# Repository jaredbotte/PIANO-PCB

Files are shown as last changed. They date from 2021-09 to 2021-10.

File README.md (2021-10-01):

# P.I.A.N.O PCB Repository
This repository currently contains all the KiCad files for the P.I.A.N.O PCB.    

To clone this repository, please run:   
```
git clone https://github.com/jaredbotte/PIANO-PCB.git
cd PIANO-PCB
git submodule init
git submodule update
```

This will ensure that you have all the required parts libraries to view our PCB.

I tried my best to ensure that all paths are relative, but if a path cannot be found, please try looking in the "manage libraries" or "manage footprints" tabs.

TODO: Prune this and include minimal files from external repositories!

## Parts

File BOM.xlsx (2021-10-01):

Part/Description | Quantity | Currently Have | MFG. Number | Supplier Number | Cost | Total | Link
Bulk Capacitor 1000µF | 1 | 0 | 35PX1000MEFC10X20 | 1189-1745-ND | 0.84 | 0.84 | https://www.digikey.com/en/products/detail/rubycon/35PX1000MEFC10X20/3563769
440Ω Resistor 0805 | 1 |  |  |  |  | 0
01x06 Pin Socket | 1 | 0 | 2044-1X07G00SA | 2553-2044-1X07G00SA-ND | 0.33 | 0.33 | https://www.digikey.com/en/products/detail/oupiin/2044-1X07G00SA/13251939
10kΩ Resistor 0805 | 3 |  |  |  |  | 0
AZ1117-3.3 | 1 |  |  |  |  | 0
10µF Capacitor 0805 | 2 |  |  |  |  | 0
0.01µF Capacitor 0805 | 1 |  |  |  |  | 0
0.1µF Capacitor 0805 | 3 |  |  |  |  | 0
DIN 5 180 degree | 1 |  |  |  |  | 0
1N914 Diode | 1 |  |  |  |  | 0
4.7kΩ Resistor 0805 | 1 |  |  |  |  | 0
50kΩ Resistor 0805 | 1 |  |  |  |  | 0
220Ω Resistor 0805 | 4 |  |  |  |  | 0
6N138 Optoisolator | 1 |  |  |  |  | 0
Blue LED 0805 | 1 |  |  |  |  | 0
Green LED 0805 | 1 |  |  |  |  | 0
22µF Capacitor | 1 |  |  |  |  | 0
74AHCT1G125W5-7 | 1 |  |  |  |  | 0
317030213 | 1 | 0 | 317030213 | 1597-1434-ND | 9.9 | 9.9 | https://www.digikey.com/en/products/detail/seeed-technology-co-ltd/317030213/6578366
Barrel Jack | 1 |  |  |  |  | 0
01x07 Pin Socket | 1 | 0 | PPTC071LFBN-RC | S7005-ND | 0.59 | 0.59 | https://www.digikey.com/en/products/detail/sullins-connector-solutions/PPTC071LFBN-RC/810146
6mmx6mm Push Button | 1 |  |  |  |  | 0
MicroSD Socket | 1 |  |  |  |  | 0
Terminal Block Connector | 1 |  |  |  |  | 0
Already Have
Lab
Order
On List

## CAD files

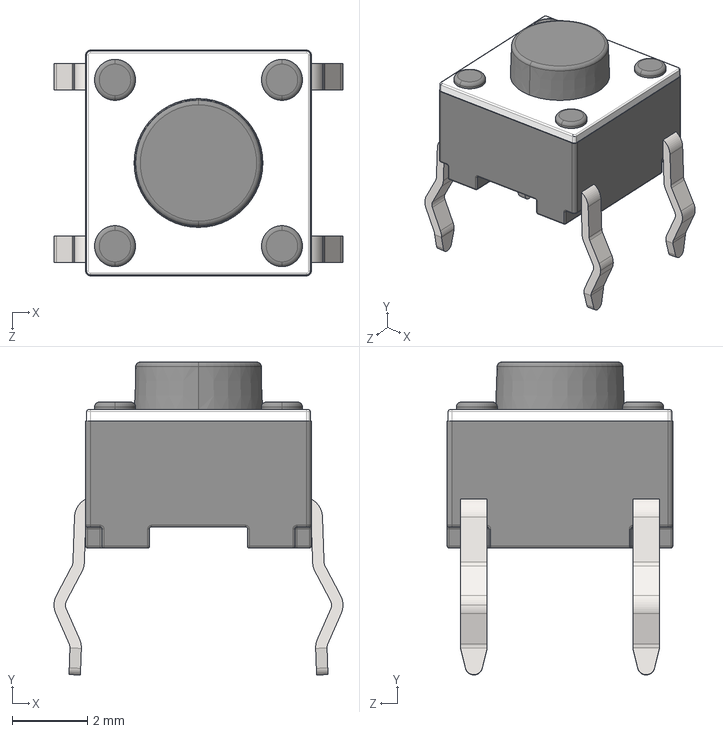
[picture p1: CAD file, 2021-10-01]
Parts/4-1437565-1/tactileswitch-short.STEP
7.69 x 8.33 x 6.01 mm

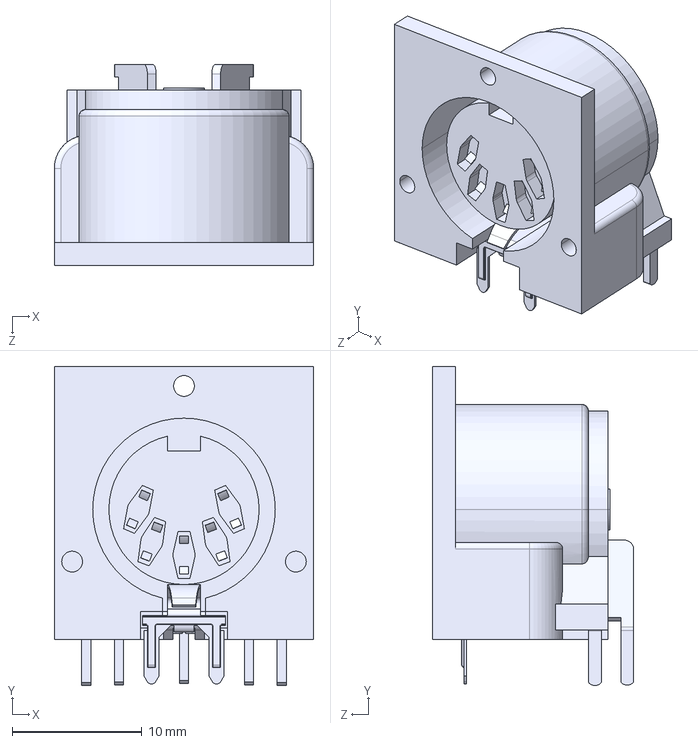
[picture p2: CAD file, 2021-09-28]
Parts/57PC5F/57PC5F--3DModel-STEP-1.STEP
20.0 x 24.5 x 15.5 mm

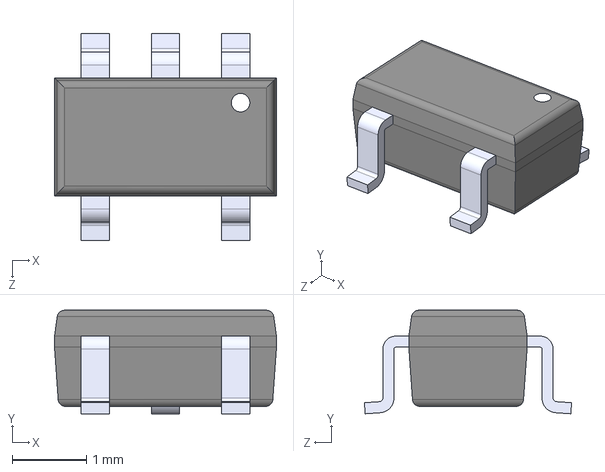
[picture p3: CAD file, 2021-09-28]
Parts/74AHCT1G125W5-7/74AHCT1G125W5-7.step
3.00 x 1.40 x 2.80 mm

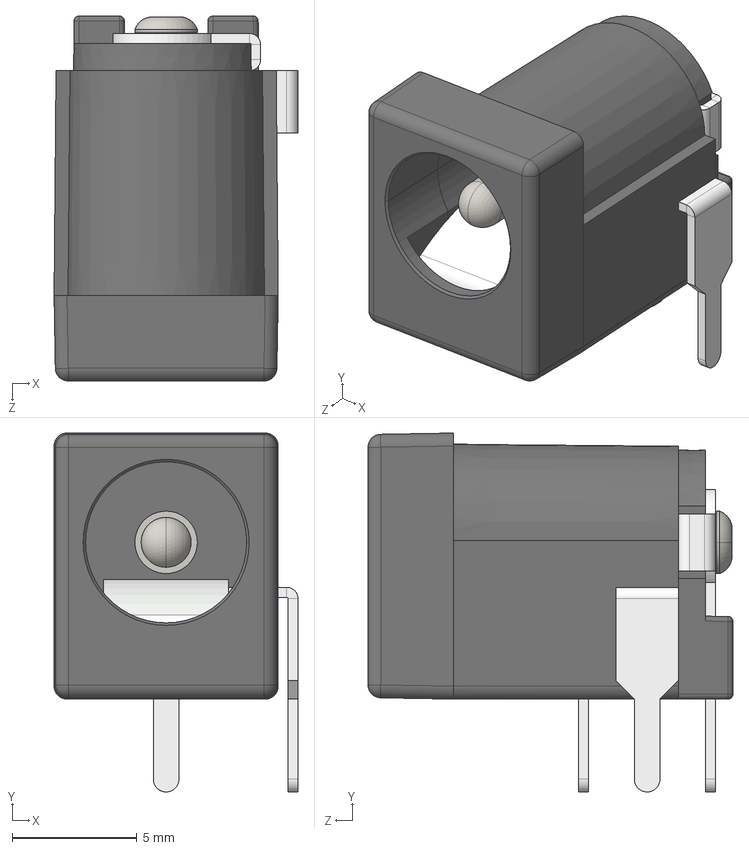
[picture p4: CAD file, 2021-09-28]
Parts/barrel_jack/DC Power Jack 5.5mm x 2.1mm.STEP
9.77 x 14.4 x 14.6 mm

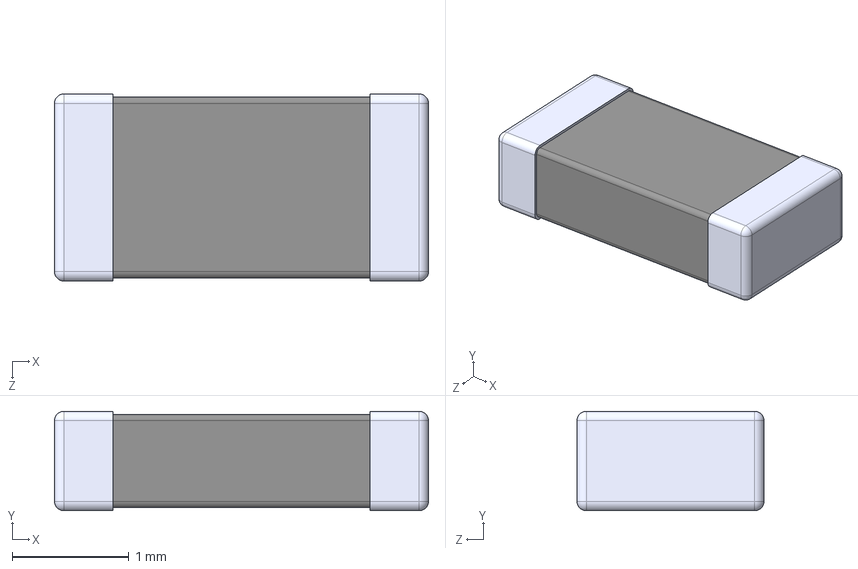
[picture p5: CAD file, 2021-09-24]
Parts/C1206C226M9PACTU/C1206C226M9PACTU.step
3.20 x 0.85 x 1.60 mm

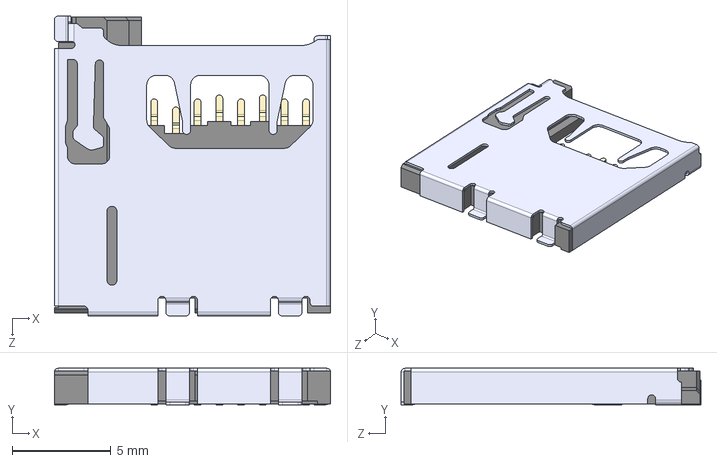
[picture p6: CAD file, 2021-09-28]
Parts/microsd/2908-05WB-MG--3DModel-STEP-56544.STEP
14.0 x 1.85 x 15.2 mm

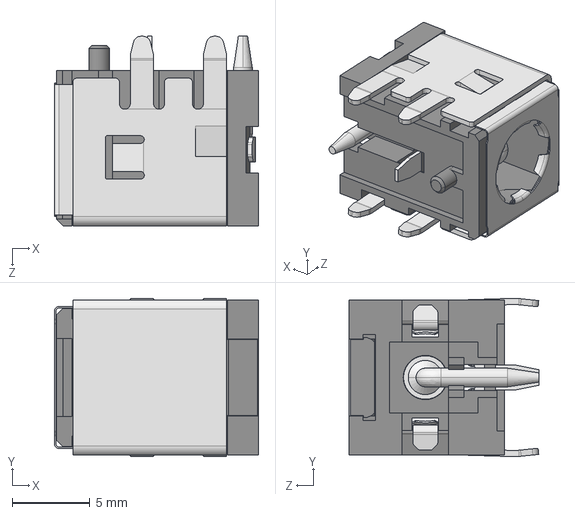
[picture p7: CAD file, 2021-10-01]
Parts/PJ-082BH/CUI_DEVICES_PJ-082BH.step
13.1 x 10.2 x 12.2 mm

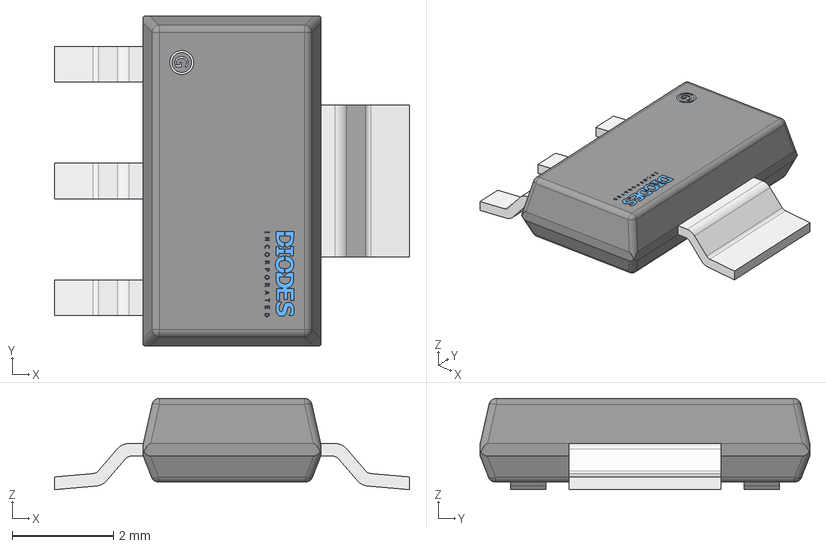
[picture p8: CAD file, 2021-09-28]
Parts/power_regulator/eec.models/Diodes_Inc._-_AZ1117H-3.3TRG1.step
7.00 x 6.50 x 1.80 mm

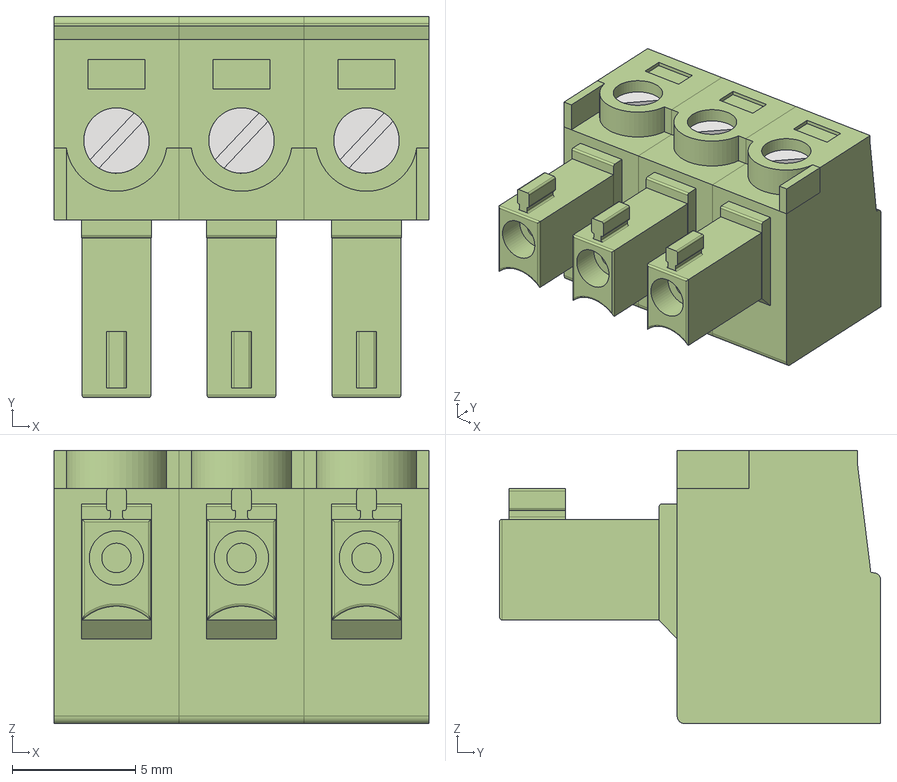
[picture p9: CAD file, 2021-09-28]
Parts/terminal_jack/15EDGK-5.08-03P-14-00A(H).stp
15.2 x 15.5 x 11.1 mm
body_1pc EC350V x 3
body_screw EC350V x 3
body_15edgk_top x 2

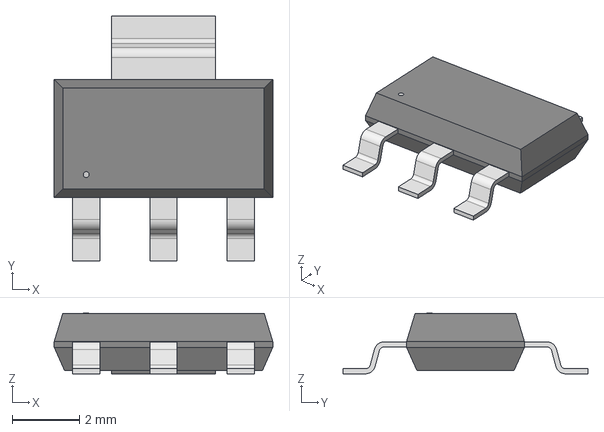
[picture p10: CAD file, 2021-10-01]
Parts/ul_AZ1117IH-3-3TRG1/KiCAD/2021-09-23_22-23-04/SOT223_AZ1117I_6P5X3P5_DIO.step
6.50 x 7.29 x 1.81 mm

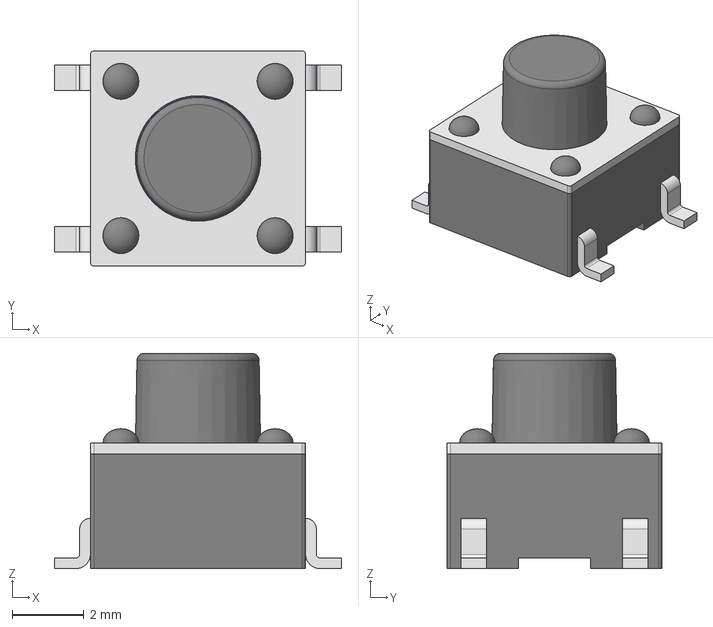
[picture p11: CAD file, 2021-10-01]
Parts/4-1437565-1/TS6-SMT_H-6.0.step
8.00 x 6.00 x 6.00 mm

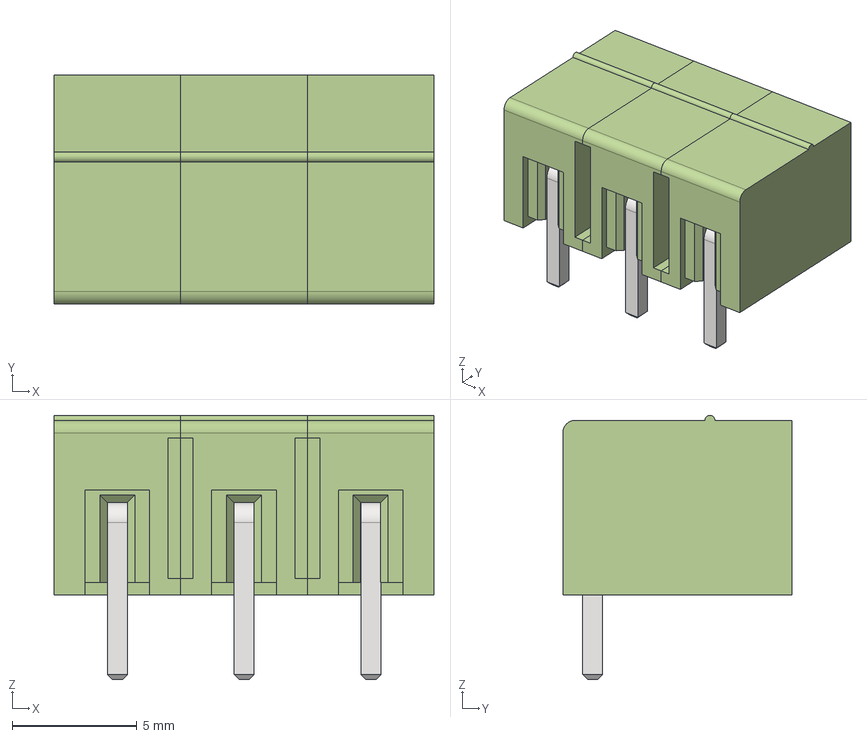
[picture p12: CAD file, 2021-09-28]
Parts/terminal_jack/15EDGRC-5.08- 03P-14-00A(H).stp
15.2 x 9.20 x 10.6 mm
body_1pc
contact x 3
body_1pc_1
body_1pc_2

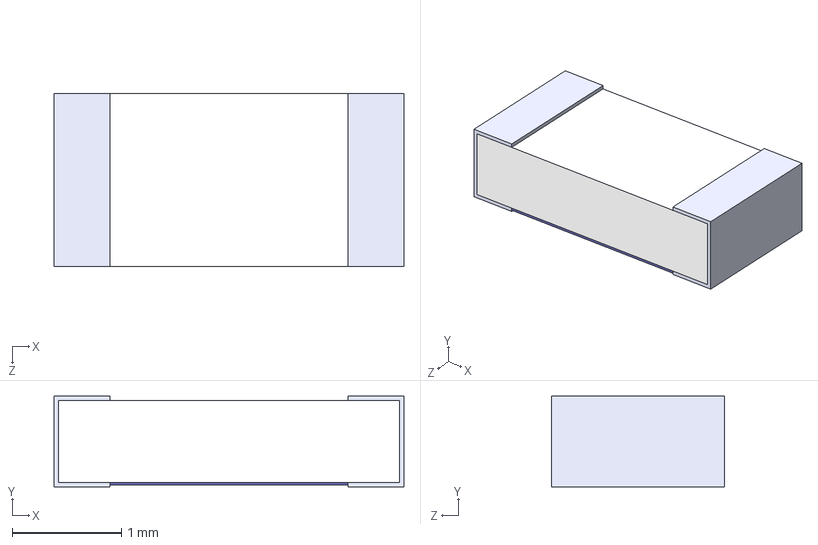
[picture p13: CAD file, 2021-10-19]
Parts/0685P8000-01/0685P8000-01.step
3.20 x 0.83 x 1.58 mm

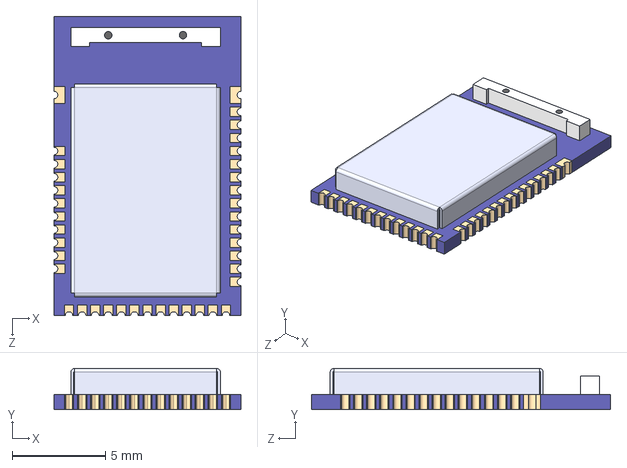
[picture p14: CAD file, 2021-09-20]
Parts/317030213/317030213.step
10.0 x 2.20 x 16.0 mm

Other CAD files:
Parts/796644-3/796644-3.step

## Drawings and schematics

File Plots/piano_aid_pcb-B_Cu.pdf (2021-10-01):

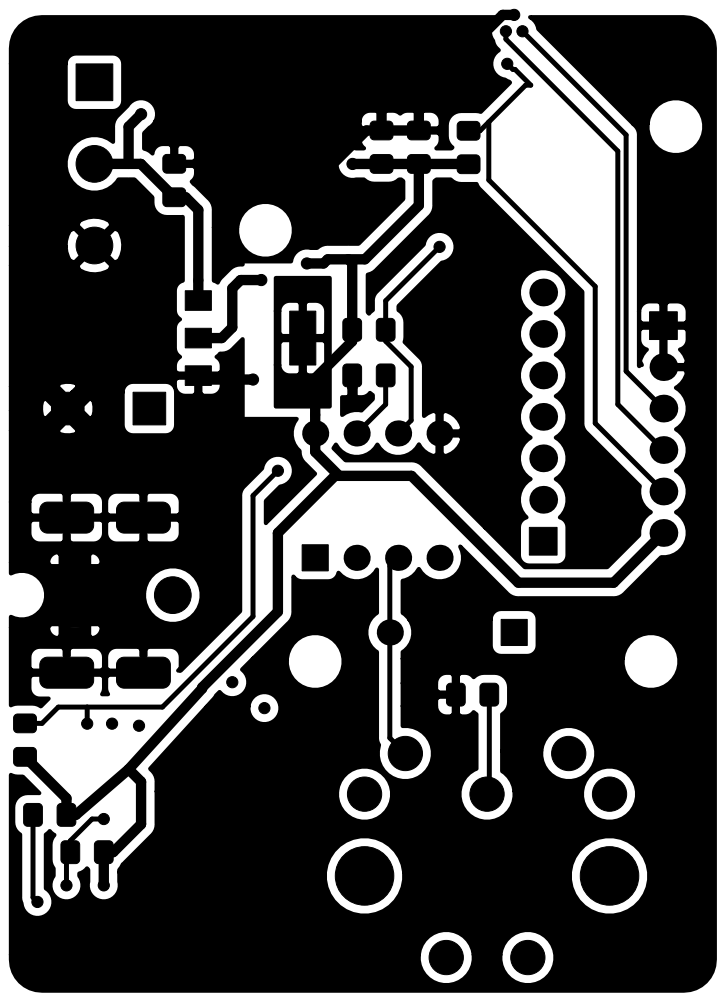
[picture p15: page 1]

File: piano_aid_pcb.kicad_pcb Sheet: Authors: Jared Botte, Jerry Jin

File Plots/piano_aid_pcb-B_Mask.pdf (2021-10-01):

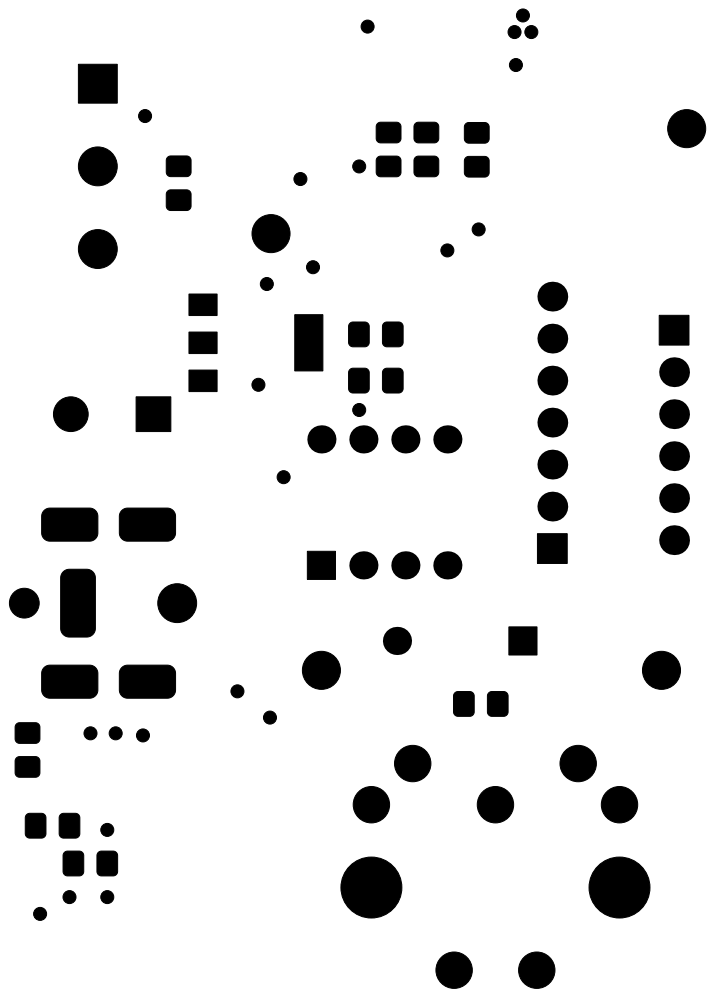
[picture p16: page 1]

File: piano_aid_pcb.kicad_pcb Sheet: Authors: Jared Botte, Jerry Jin

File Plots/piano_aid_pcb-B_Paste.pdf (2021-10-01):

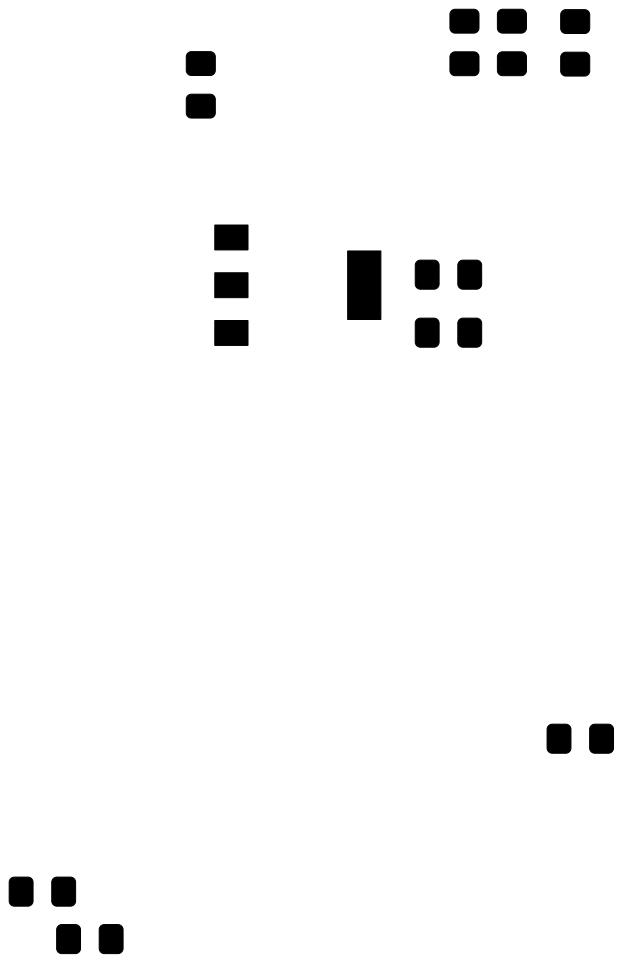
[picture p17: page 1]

File: piano_aid_pcb.kicad_pcb Sheet: Authors: Jared Botte, Jerry Jin

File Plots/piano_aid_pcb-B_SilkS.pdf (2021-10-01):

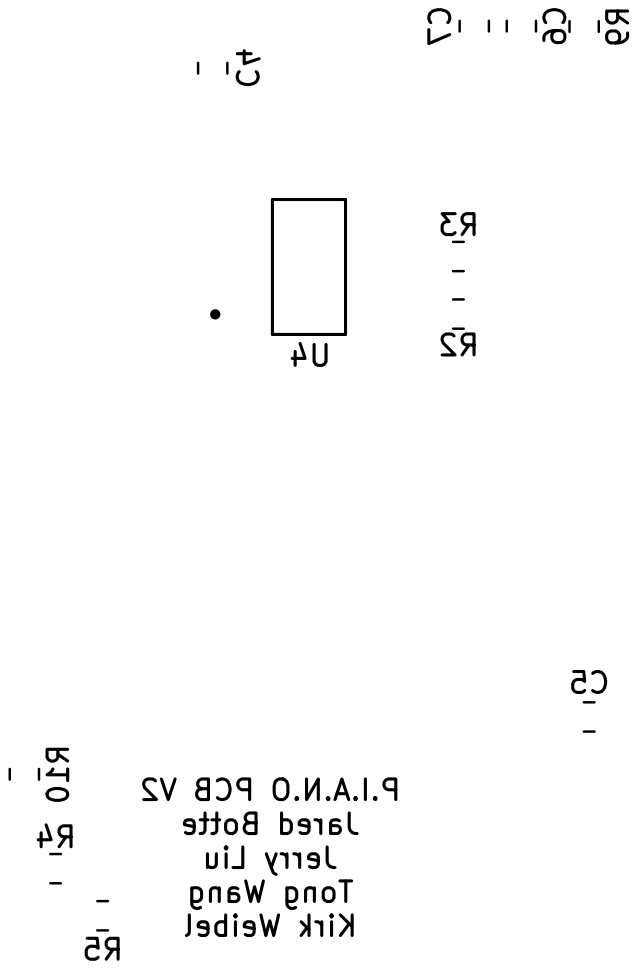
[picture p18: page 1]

File: piano_aid_pcb.kicad_pcb Sheet: Authors: Jared Botte, Jerry Jin

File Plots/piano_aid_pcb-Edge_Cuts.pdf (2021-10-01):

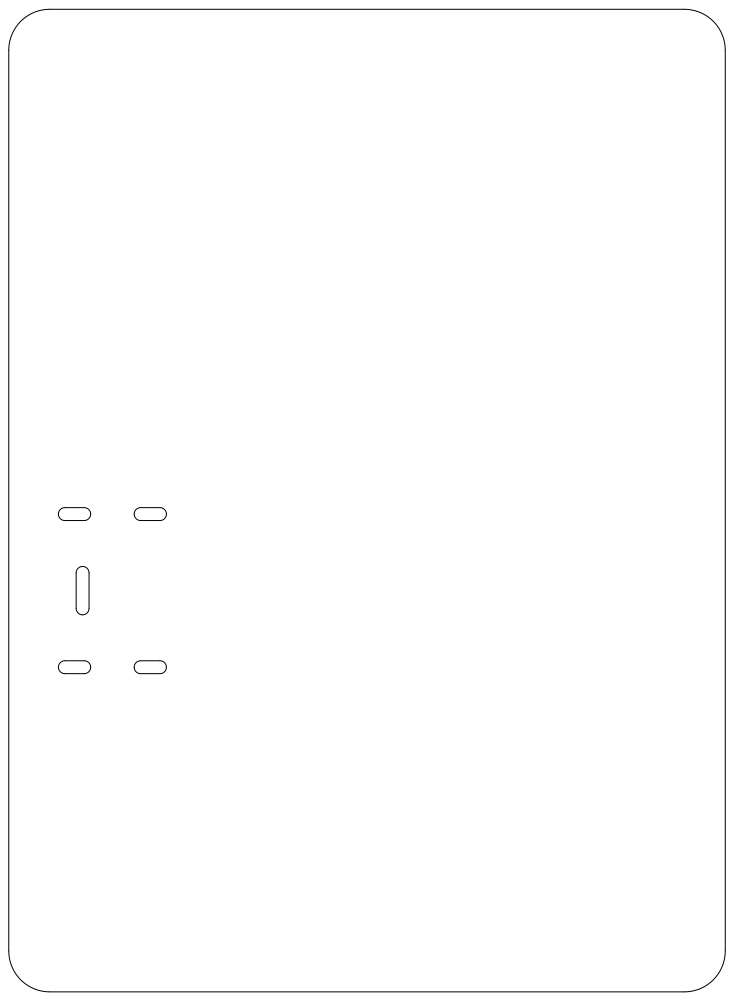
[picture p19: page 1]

File: piano_aid_pcb.kicad_pcb Sheet: Authors: Jared Botte, Jerry Jin

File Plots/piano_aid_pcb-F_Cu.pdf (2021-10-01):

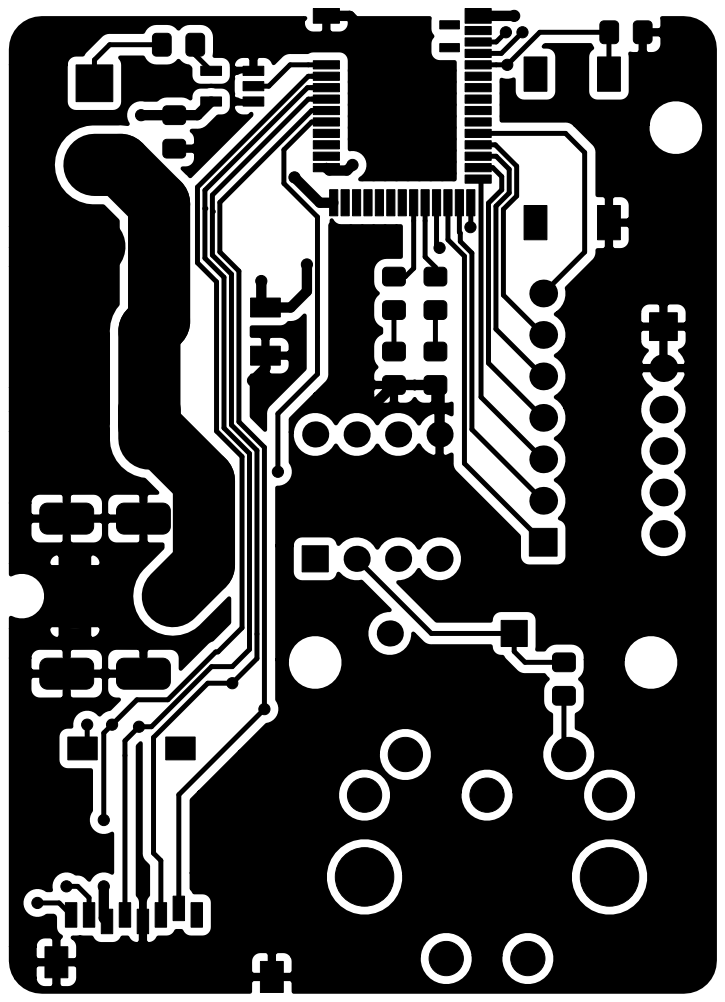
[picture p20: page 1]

File: piano_aid_pcb.kicad_pcb Sheet: Authors: Jared Botte, Jerry Jin

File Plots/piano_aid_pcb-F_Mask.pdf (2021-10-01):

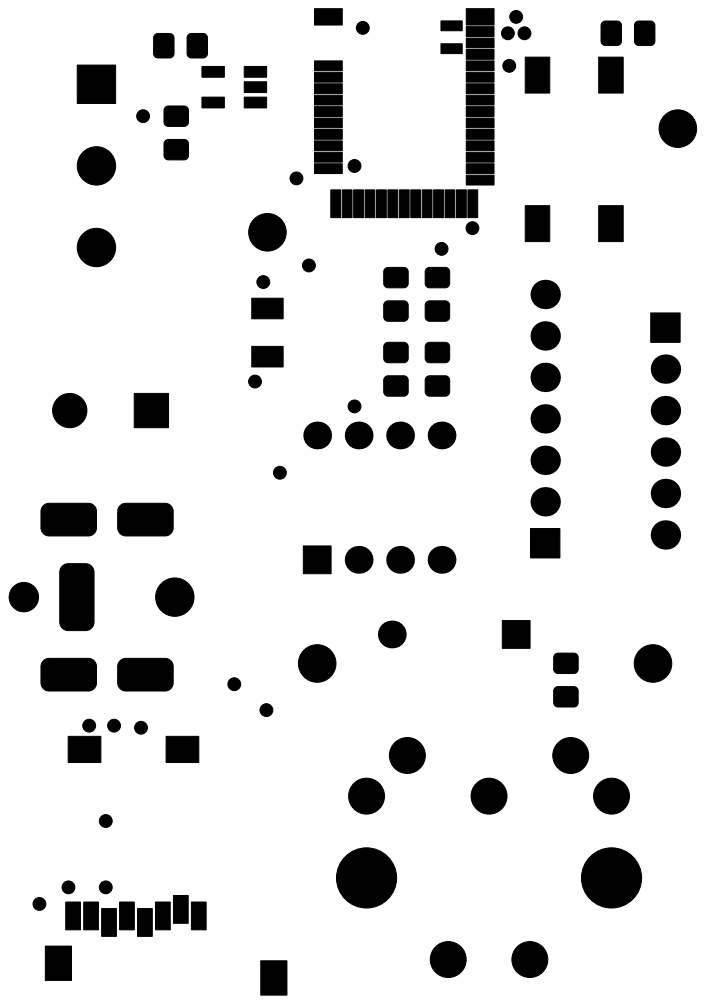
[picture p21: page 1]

File: piano_aid_pcb.kicad_pcb Sheet: Authors: Jared Botte, Jerry Jin

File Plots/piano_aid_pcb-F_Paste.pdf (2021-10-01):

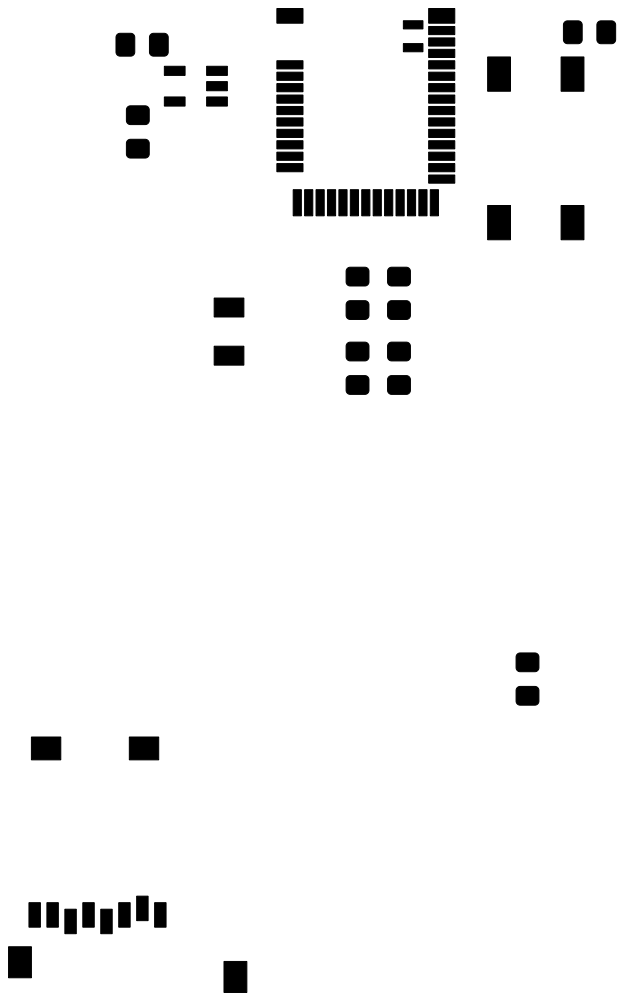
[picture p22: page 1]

File: piano_aid_pcb.kicad_pcb Sheet: Authors: Jared Botte, Jerry Jin

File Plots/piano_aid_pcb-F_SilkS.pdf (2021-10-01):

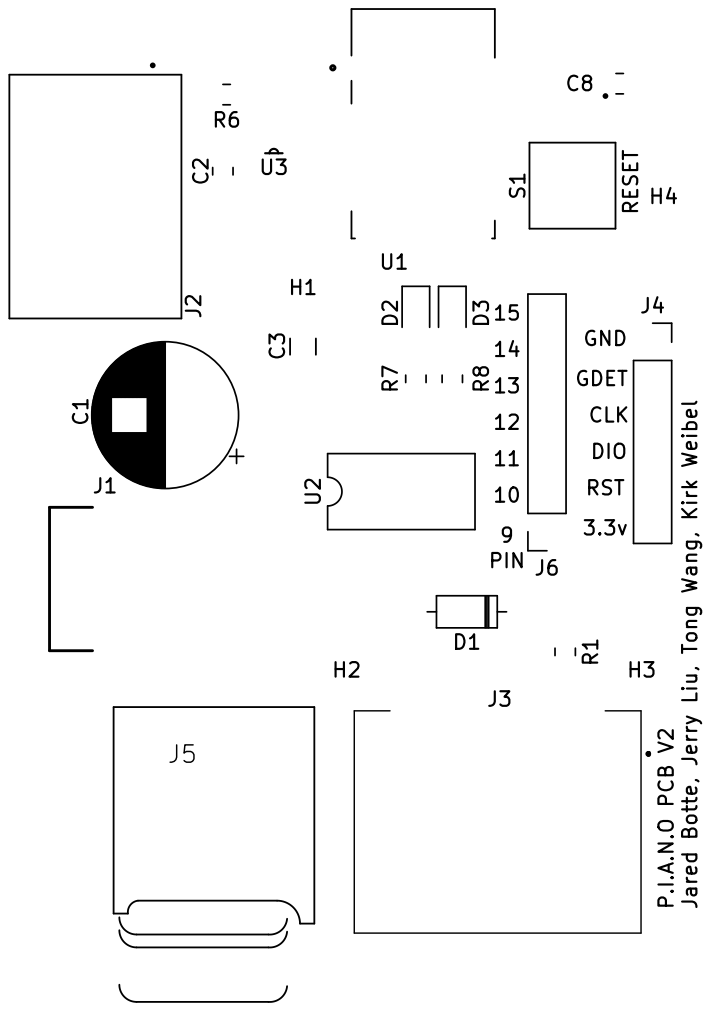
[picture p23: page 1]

File: piano_aid_pcb.kicad_pcb Sheet: Authors: Jared Botte, Jerry Jin

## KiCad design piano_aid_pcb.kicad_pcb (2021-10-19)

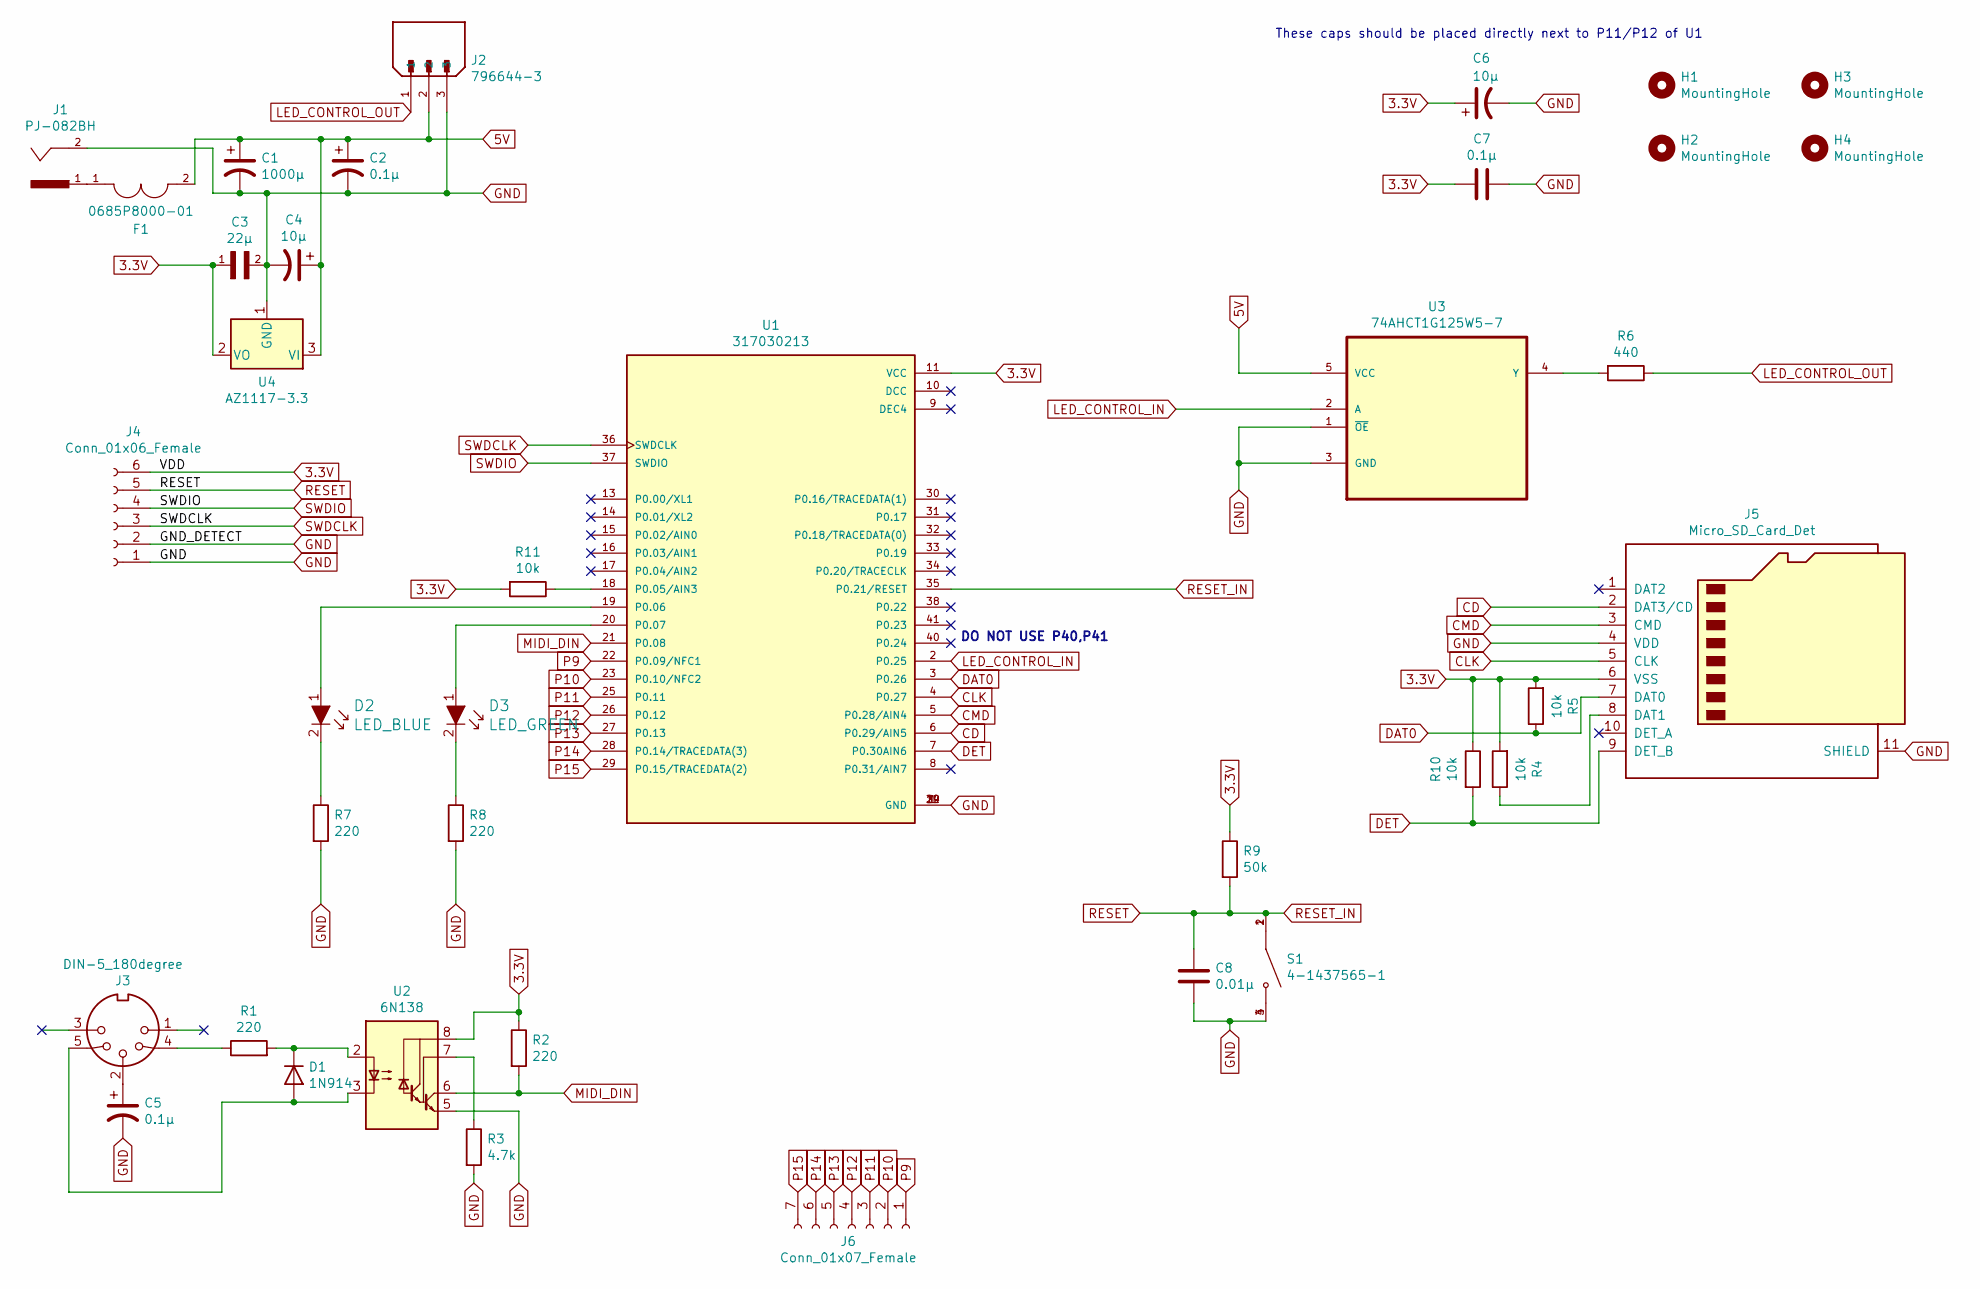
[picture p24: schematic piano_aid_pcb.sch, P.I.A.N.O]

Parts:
C1: 1000µ; CP_Radial_D10.0mm_P5.00mm
C2, C5, C7: 0.1µ; C_0805_2012Metric_Pad1.15x1.40mm_HandSolder
C3: 22µ; CAPC3216X110N
C4, C6: 10µ; C_0805_2012Metric_Pad1.15x1.40mm_HandSolder
C8: 0.01µ; C_0805_2012Metric_Pad1.15x1.40mm_HandSolder
D1: 1N914; D_DO-35_SOD27_P7.62mm_Horizontal
D2: LED_BLUE; LED_0805_2012Metric_Pad1.15x1.40mm_HandSolder; MPN LTST-C191TBKT; Digi-Key_PN 160-1647-1-ND
D3: LED_GREEN; LED_0805_2012Metric_Pad1.15x1.40mm_HandSolder; MPN LG L29K-G2J1-24-Z; Digi-Key_PN 475-2709-1-ND
F1: 0685P8000-01; FUSC3215X83N; PARTREV Jan2019
H1, H2, H3, H4: MountingHole; MountingHole_2.2mm_M2
J1: PJ-082BH; CUI_PJ-082BH
J2: 796644-3; TE_796644-3
J3: DIN-5_180degree; 57PC5F
J4: Conn_01x06_Female; PinSocket_1x06_P2.54mm_Vertical
J5: Micro_SD_Card_Det; MICROSD
J6: Conn_01x07_Female; PinSocket_1x07_P2.54mm_Vertical
R1, R2, R7, R8: 220; R_0805_2012Metric_Pad1.15x1.40mm_HandSolder
R3: 4.7k; R_0805_2012Metric_Pad1.15x1.40mm_HandSolder
R4, R5, R10, R11: 10k; R_0805_2012Metric_Pad1.15x1.40mm_HandSolder
R6: 440; R_0805_2012Metric_Pad1.15x1.40mm_HandSolder
R9: 50k; R_0805_2012Metric_Pad1.15x1.40mm_HandSolder
S1: 4-1437565-1; SW_4-1437565-1
U1: 317030213; XCVR_317030213
U2: 6N138; DIP-8_W7.62mm
U3: 74AHCT1G125W5-7; SOT95P280X140-5N; MPN 74AHCT1G125W5-7
U4: AZ1117-3.3; Diodes_Inc.-SOT223-03_2017-0-MFG

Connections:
3.3V: C3.1, C6.1, C7.2, J4.6, J5.6 (VSS), R2.1, R4.2, R5.2, R9.1, R10.1, R11.2, U1.11 (VCC), U2.8 (VCC), U4.2 (VO)
5V: C1.1, C2.1, C4.1, F1.2, J2.2, U3.5 (VCC), U4.3 (VI)
CD: J5.2 (DAT3/CD), U1.6 (P0.29/AIN5)
CLK: J5.5 (CLK), U1.4 (P0.27)
CMD: J5.3 (CMD), U1.5 (P0.28/AIN4)
DAT0: J5.7 (DAT0), R5.1, U1.3 (P0.26)
DET: J5.9 (DET_B), R10.2, U1.7 (P0.30AIN6)
GND: C1.2, C2.2, C3.2, C4.2, C5.2, C6.2, C7.1, C8.2, J1.2, J2.3, J4.1, J4.2, J5.4 (VDD), J5.11 (SHIELD), R3.2, R7.2, R8.2, S1.3, S1.4, U1.1 (GND), U1.12 (GND), U1.24 (GND), U1.39 (GND), U2.5 (GND), U3.1 (~OE), U3.3 (GND), U4.1 (GND)
LED_CONTROL_IN: U1.2 (P0.25), U3.2 (A)
LED_CONTROL_OUT: J2.1, R6.1
MIDI_DIN: R2.2, U1.21 (P0.08), U2.6 (VO2)
unnamed: C5.1, J3.2
unnamed: D1.1 (K), R1.2, U2.2 (C1)
unnamed: D1.2 (A), J3.5, U2.3 (C2)
unnamed: D2.1, U1.19 (P0.06)
unnamed: D2.2, R7.1
unnamed: D3.1, U1.20 (P0.07)
unnamed: D3.2, R8.1
unnamed: F1.1, J1.1
unnamed: J3.4, R1.1
unnamed: J5.8 (DAT1), R4.1
unnamed: R3.1, U2.7 (VO1)
unnamed: R6.2, U3.4 (Y)
unnamed: R11.1, U1.18 (P0.05/AIN3)
P9: J6.1, U1.22 (P0.09/NFC1)
P10: J6.2, U1.23 (P0.10/NFC2)
P11: J6.3, U1.25 (P0.11)
P12: J6.4, U1.26 (P0.12)
P13: J6.5, U1.27 (P0.13)
P14: J6.6, U1.28 (P0.14/TRACEDATA(3))
P15: J6.7, U1.29 (P0.15/TRACEDATA(2))
RESET: C8.1, J4.5, R9.2, S1.1, S1.2, U1.35 (P0.21/RESET)
SWDCLK: J4.3, U1.36 (SWDCLK)
SWDIO: J4.4, U1.37 (SWDIO)

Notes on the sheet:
These caps should be placed directly next to P11/P12 of U1
DO NOT USE P40,P41

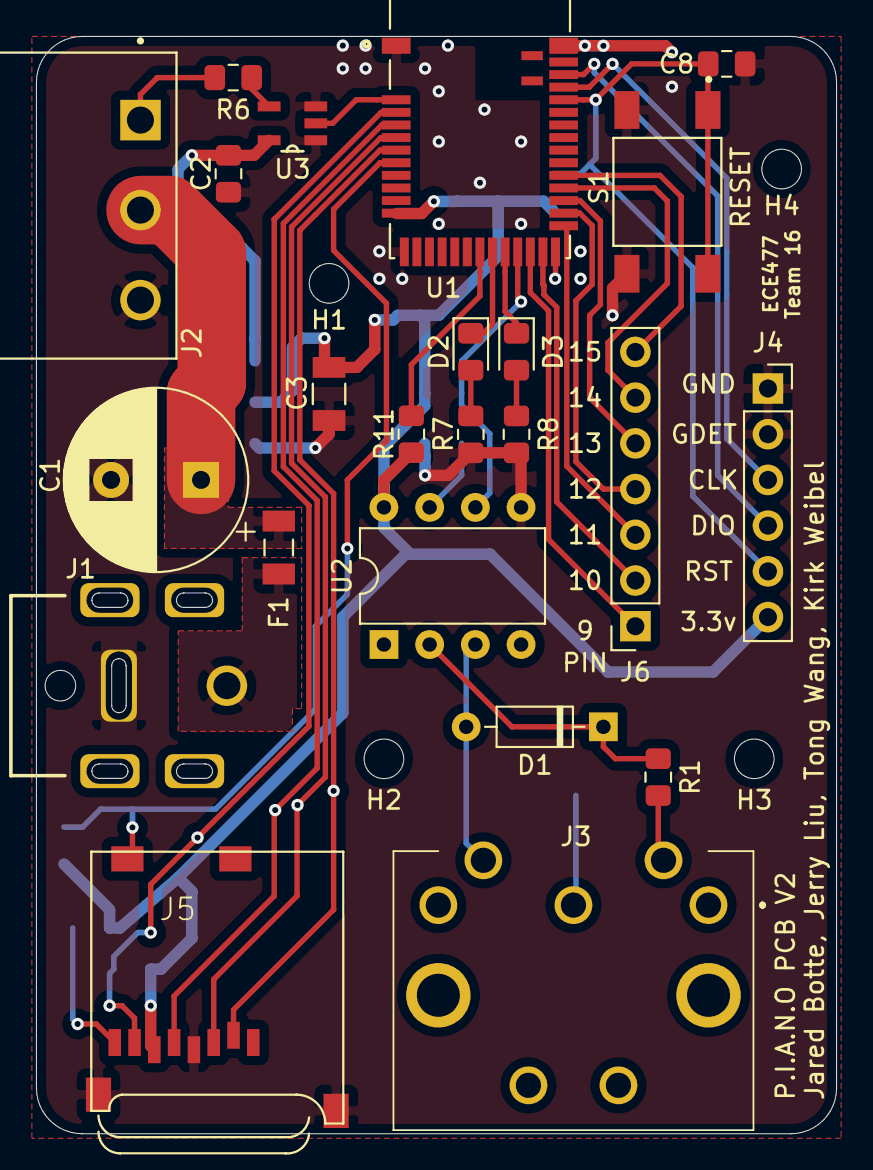
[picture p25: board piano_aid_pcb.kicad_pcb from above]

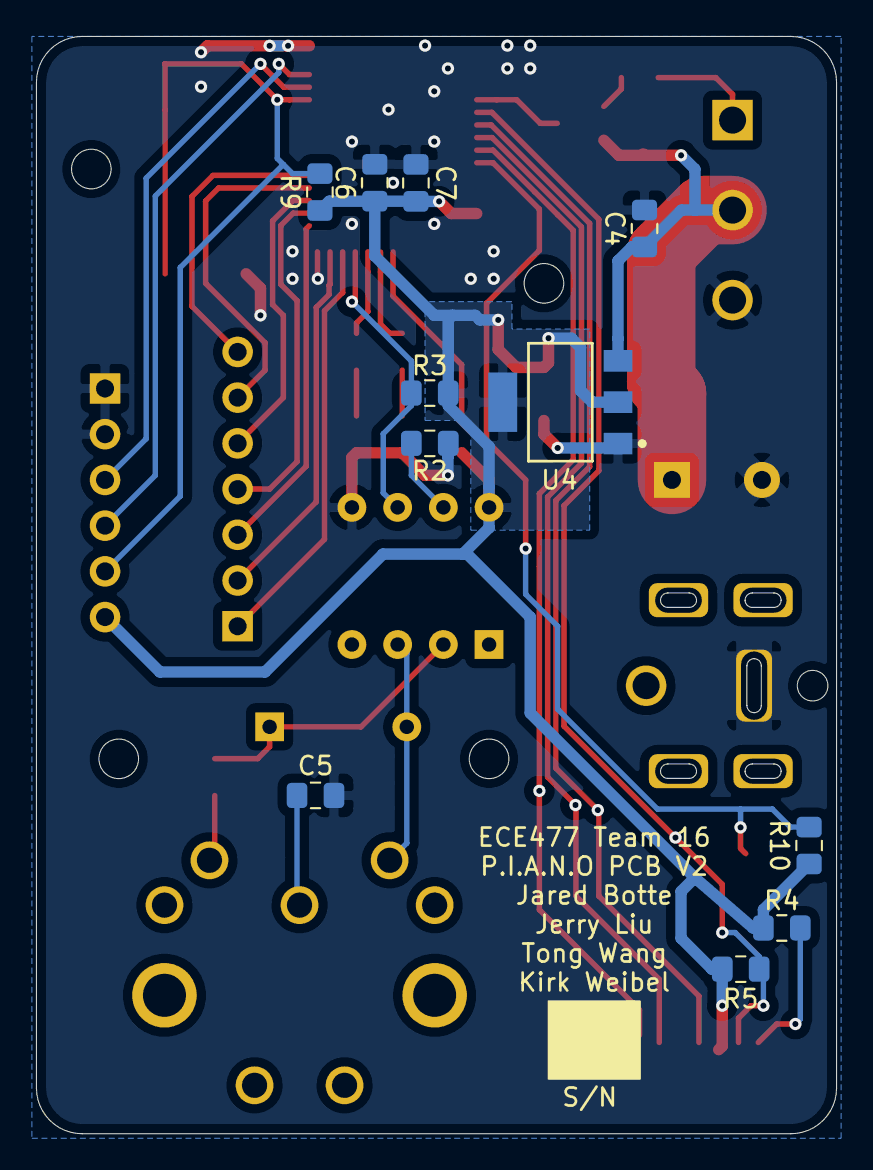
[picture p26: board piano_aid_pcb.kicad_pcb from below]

Board: 2 copper layers, 44.5 x 61.0 mm, 38 parts (11 on the bottom side), 34 nets.

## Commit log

2021-09-15 Initial commit. Board includes main chip, microsd, barrel jack, and MIDI DIN circuit.
    [piano_aid_pcb.kicad_pcb, piano_aid_pcb.sch]
2021-09-17 Added screw terminal and power regulation
    [piano_aid_pcb.sch]
2021-09-17 Added more connections
    [piano_aid_pcb.sch]
2021-09-17 Added more caps
    [piano_aid_pcb.sch]
2021-09-17 Added power supply to logic level converter
    [piano_aid_pcb.sch]
2021-09-18 Updated MIDI-DIN
    [piano_aid_pcb.kicad_pcb, piano_aid_pcb.sch]
2021-09-18 Added sdcard pull up to unused pin per kingston specifications
    [piano_aid_pcb.sch]
2021-09-18 Added Jerry to authors
    [piano_aid_pcb.sch]
2021-09-19 Added component labels
    [piano_aid_pcb.sch]
2021-09-20 Moved parts folder to be inside PCB directory. This should fix broken links to references
2021-09-20 Added parts folder
    [317030213.step]
2021-09-21 Added LEDs, fixed absolute paths linked to my specific path
    [piano_aid_pcb.sch]
2021-09-23 Added refs to components
    [piano_aid_pcb.sch]
2021-09-23 Added kicad libraries from adafruit and digkey
    [piano_aid_pcb.sch]
2021-09-23 Added adafruit eagle libraries. Also Started assigning components to footprints
    [piano_aid_pcb.sch]
2021-09-24 Started board layout. Finished footprints
    [C1206C226M9PACTU.step, piano_aid_pcb.kicad_pcb, piano_aid_pcb.sch]
2021-09-28 Made PCB. Not happy with the traces, may try again. For now this is 95% complete.
    [15EDGK-5.08-03P-14-00A(H).stp, 15EDGRC-5.08- 03P-14-00A(H).stp, 2908-05WB-MG--3DModel-STEP-56544.STEP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]
2021-09-29 Completely re-traced and layed out board. Presenting PCB V2
    [TS6-SMT_H-6.0.step, piano_aid_pcb.kicad_pcb, piano_aid_pcb.sch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]
2021-09-29 Made some adjustments. Fixed silkscreen. Added team info.
    [piano_aid_pcb.kicad_pcb, piano_aid_pcb.sch]
2021-09-29 Fixed some silkscreen issues. Also fixed microsd footprint and added chip detect functionality
    [piano_aid_pcb.kicad_pcb, piano_aid_pcb.sch]
2021-09-29 Added BOM
    [BOM.xlsx]
2021-09-30 Changed out barrel jack. Still needs to be connected to ground. I think there's an issue with the footprint. Also rounded the edges of the board.
    [BOM.xlsx, CUI_DEVICES_PJ-082BH.step, piano_aid_pcb.kicad_pcb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]
2021-10-01 Created new plots, fixed barrel jack footprint, added thermal pad for power regulator, fixed fills. Instructors approve so far.
    [piano_aid_pcb.kicad_pcb]
2021-10-01 Added power reg 3d model
    [SOT223_AZ1117I_6P5X3P5_DIO.step]
2021-10-05 Fixed absolute paths, added pull up resistor.
    [piano_aid_pcb.kicad_pcb, piano_aid_pcb.sch]
2021-10-07 Made schematic a bit neater
    [piano_aid_pcb.kicad_pcb, piano_aid_pcb.sch]
2021-10-07 Fixed keepout zone, cleaned traces
    [piano_aid_pcb.kicad_pcb]
2021-10-08 increased 3.3v plane on footprint
    [piano_aid_pcb.kicad_pcb, piano_aid_pcb.sch]
2021-10-12 Made final changes, added team/course number, fixed reset button pinout
    [piano_aid_pcb-B_Cu.gbl, piano_aid_pcb-B_Mask.gbs, piano_aid_pcb-B_SilkS.gbo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]
2021-10-13 Added via for button second ground
    [piano_aid_pcb.kicad_pcb]
2021-10-13 Removed unused libraries to reduce project size
    [piano_aid_pcb.kicad_pcb]
2021-10-19 Added 1206 fuse
    [0685P8000-01.step, piano_aid_pcb.kicad_pcb, piano_aid_pcb.sch]
2021-10-19 Added reccomended vias
    [piano_aid_pcb.kicad_pcb]
2021-10-19 Fixed thermal reliefs
    [piano_aid_pcb.kicad_pcb]
